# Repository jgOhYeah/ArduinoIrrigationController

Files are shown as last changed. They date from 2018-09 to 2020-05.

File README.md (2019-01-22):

# Arduino Irrigation Controller
An irrigation controller for a small farm that remotely controls a set of linear actuators that raise and lower flaps over pipes.
## This is still a WORK IN PROGRESS!
I am mainly using this repository to transfer files! If you are interested in using this, have a look at `SlaveUnit/SlaveUnit3.6` and `Controller/3.4`. **There will be bugs!**
## Links
Most of these notes are very out of date and based off old versions - I have not properly updated the documentation for quite a while!
- [User Guide](Documentation/UserGuide.md)
- [Technical Notes and rambling](Documentation/TechnicalNotes)
# Parts
## Master
- Arduino Mega
- 3 buttons (left, right and select)
- Character lcd (currently using a 40 by 2 lcd, also works on a 16 by 2 lcd by selecting macros and `#defines`, could be modified for a 20 by 4).
## Slaves
- Arduino Uno / Nano / Atmega328p driving a H bridge motor driver to power a linear actuator opening and shutting the bay outlets

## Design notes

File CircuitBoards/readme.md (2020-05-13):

Please note that these are a work in progress.

The slave circuit and layout is about done, I am waiting to finish the slave design and build several of them to test lots of devices on the bus before I do the master board layout.

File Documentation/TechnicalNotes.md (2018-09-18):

# Arduino Irrigation Controller Technical Notes
## Links
- [Home Page](../README.md)
- [User Guide](Documentation/UserGuide.md)
## Error Codes
Here is a list of possible error codes that will be displayed on the main controller's lcd display. All error messages start with the up time at which they were encountered followed by the details.

### `hh:mm Bays x,y,z Disconnected`
This is the most common error and is displayed when the controller does not recieve an acknowledgement from the bay outlet. If all bay outlets are effected, `All` will be displayed instead of outlet numbers. Check that everything is connected properly and turned on.

### `hh:mm `
Blah blah blah
## LCD Layout
The main controller currently uses a 16 by 2 alphanumeric lcd display. This works fairly well for displaying the seven bays that this system was designed for, however you might want to get a bigger 20 by 4 lcd and adapt the code if you plan on having more bays.

The `*` (Astrixes) are used as buttons and can be clicked on by using the left and right buttons to navigate the cursor (black line under a character) and the select button to click it.
#### Main Screen
```
                     \/ A is an option to control all bays at once.
Bay Number -> 1234567A   hh:mm
Bay Status -> ???????*   *More
```
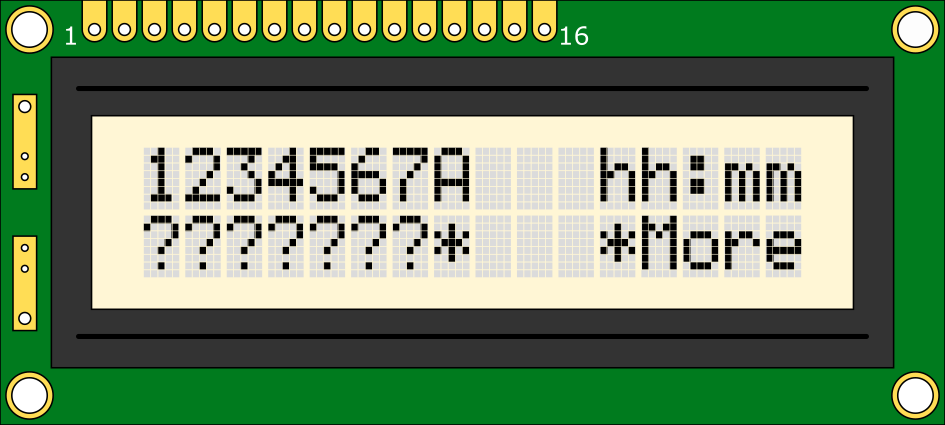
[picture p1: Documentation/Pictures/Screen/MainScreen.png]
Main Screen

#### More Options Screen
```
*Home *Reset All
*Last Error Msg
```
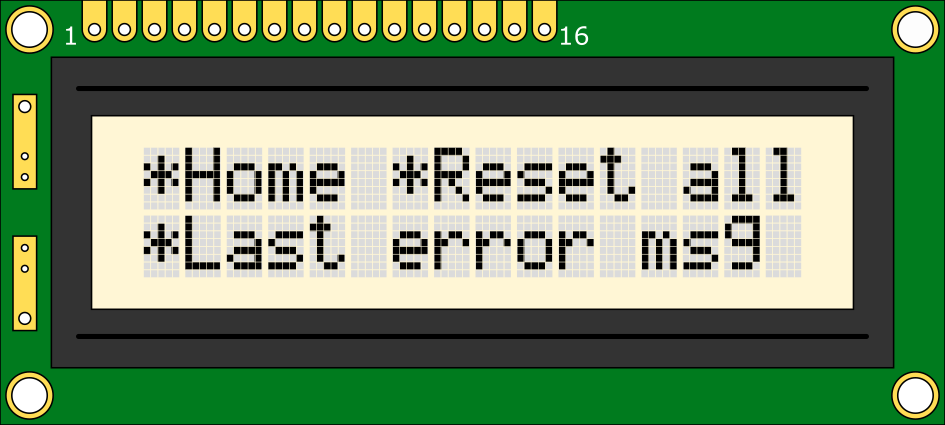
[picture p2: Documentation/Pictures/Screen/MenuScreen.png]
More Options Screen

#### Error Message Screen
```
*Home ERRORhh:mm
<Error message here. It can be scrolled as well!>
```
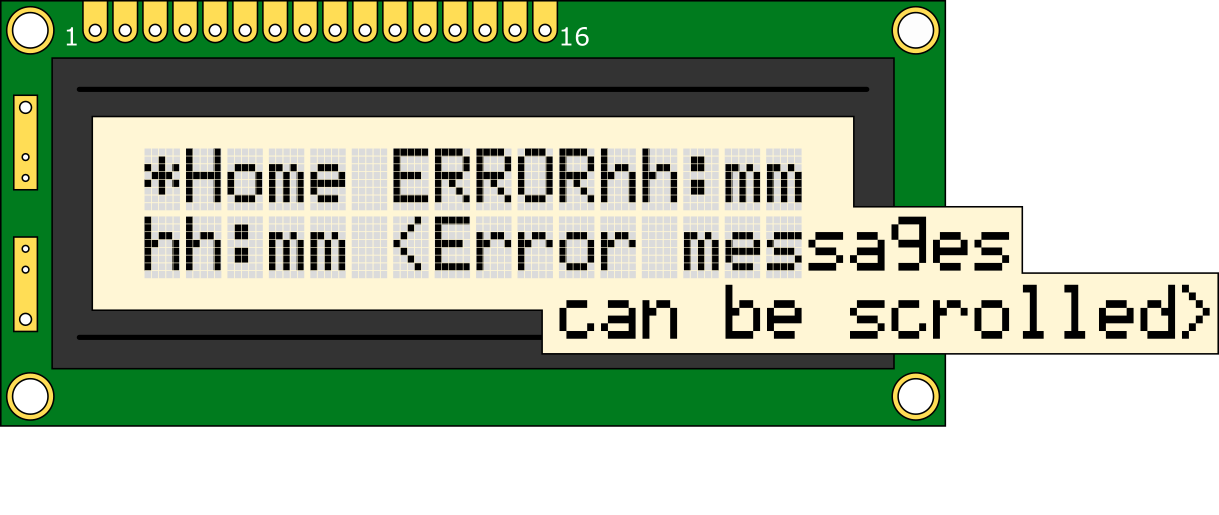
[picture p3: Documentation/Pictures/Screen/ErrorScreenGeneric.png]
Error Screen

## Communication
This system uses the PJON protocol using ThroughSerial over rs485. This protocol automatically handles error checking and making sure that packets go to where they need to go and are recieved. [Click Here](https://www.pjon.org/) to go to the PJON website.

The baud rate is set to 9600 by default. If there is large amount of data being lost, try slowing this down. The baud rate **must** be the same on all devices.

### Addresses
The bus id is set to 0.0.0.1 by default. It does not really matter as long as separate PJON networks are kept separate, but this can be changed as long as it is the same for all devices on this network.

The main controller's address is 255.

Slave addresses start at 40 for bay 1.
### Commands
The first byte of the payload in a packet contains the command. Subsequent bytes have the details.
#### `reportStatus` or `s`

The main controller sends this command when it first starts up to check which dbays are connected and see if they know their position (The main controller might be reset while everything else still has power...).
#### `overwriteStatus` or `w`
This is sent from a slave to the main controller to change what state it thinks it is in. this is used if a user presses the button on a bay outlet to change its position or after the slave has recieved a `reportStatus` command.

1 byte after the command contains the status.

#### `reset` or `x`
This is a broadcast command that should in theory reset the whole system.

#define setStatus "r"

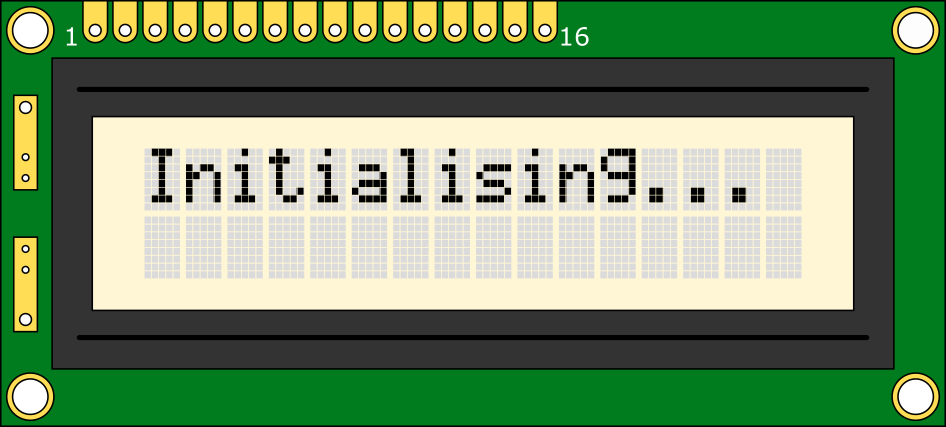
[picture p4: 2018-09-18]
Documentation/Pictures/Screen/InitScreen.png

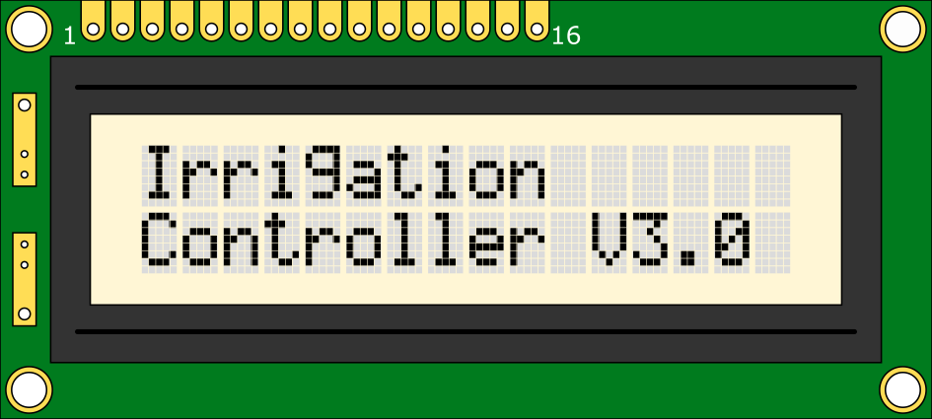
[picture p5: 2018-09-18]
Documentation/Pictures/Screen/StartupScreen.png

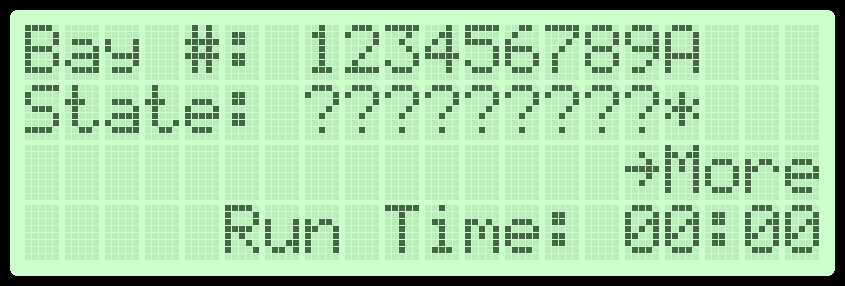
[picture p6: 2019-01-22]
OtherStuff/LCD_Plans/screenshot (2).png

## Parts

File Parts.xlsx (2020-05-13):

Item | Number On Master | Number on Slave | Total Number | Cost at number | Total Part Cost | Possible source | Total Cost | Number of slaves | Number of masters
Buttons | 3 | 1 | 10 | 4.45 | 44.5 | https://www.jaycar.com.au/ip67-rated-dome-pushbutton-switch-red/p/SP0657 | 884.5 | 7 | 1
Slave Box | 0 | 1 | 7 | 10 | 70
Master Box | 1 | 0 | 1 | 15 | 15
Linear Actuators | 0 | 1 | 7 | 100 | 700
Motor Driver | 0 | 1 | 7 | 3 | 21
Slave Circuit boards | 0 | 1.43 | 10 | 1 | 10
Master Circuit boards | 1 | 0 | 1 |  | 0
Slave Box | 0 | 1 | 7 |  | 0
Master Box | 1 | 0 | 1 |  | 0
Plugs | 1 | 1 | 8 |  | 0
Sockets | 2 | 2 | 16 |  | 0
Cable Glands | 1 | 1 | 8 | 3 | 24
 |  |  | 0 |  | 0
 |  |  | 0 |  | 0
 |  |  | 0 |  | 0
 |  |  | 0 |  | 0

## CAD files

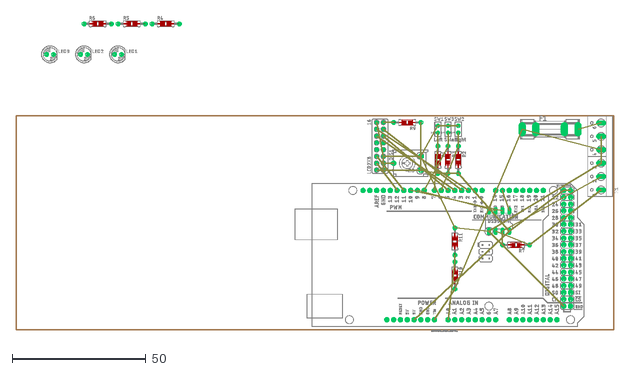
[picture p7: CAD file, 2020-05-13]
CircuitBoards/IrrigationControllerMaster/IrrigationControllerMaster.dxf
224.7 x 117.8

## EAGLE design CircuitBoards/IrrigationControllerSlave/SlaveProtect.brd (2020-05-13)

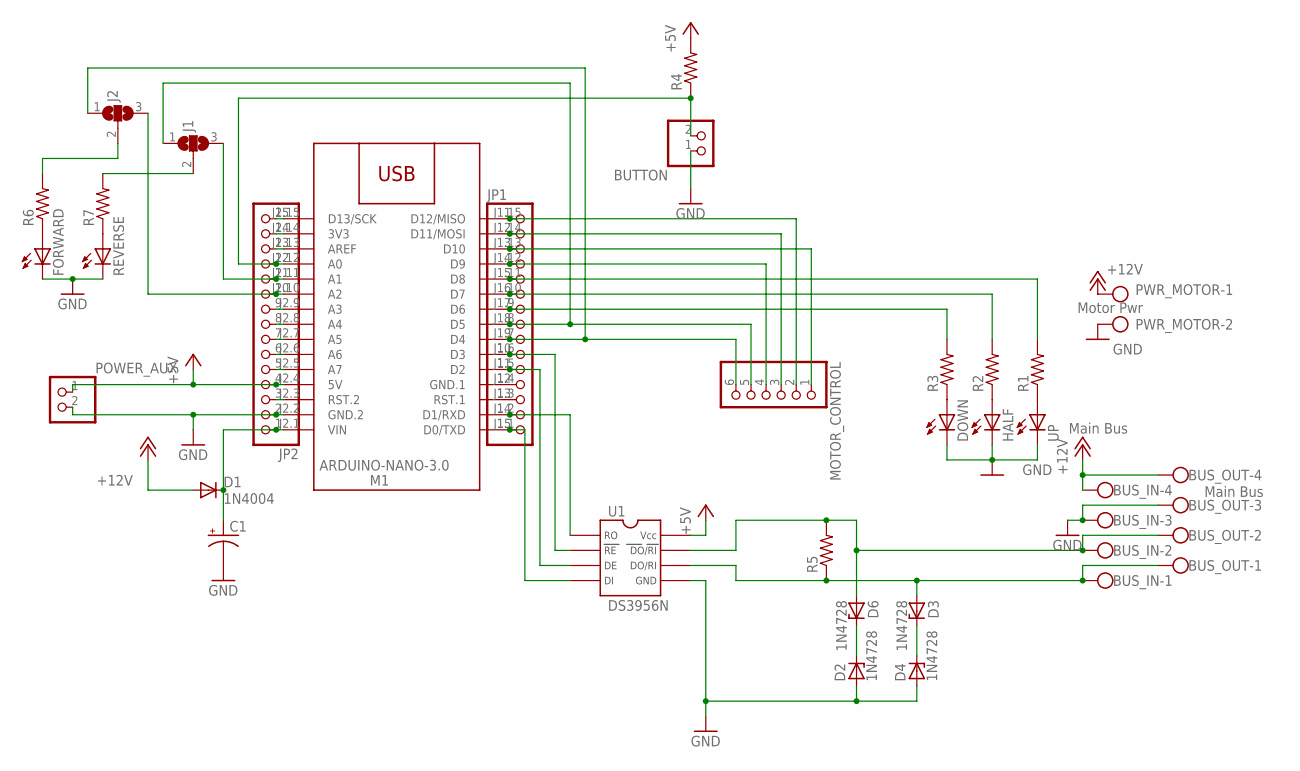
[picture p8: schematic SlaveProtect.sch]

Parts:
BUS_IN: Main Bus; W237-4
BUS_OUT: Main Bus; W237-4
BUTTON: PINHD-1X2; 1X02
C1: CPOL-USE3.5-10; E3,5-10
D1: 1N4004; DO41-10
D2, D3, D4, D6: 1N4728; DO41Z10
DOWN: LED5MM
FORWARD: LED5MM
HALF: LED5MM
J1, J2: SJ2W; SJ_2
JP1, JP2: PINHD-1X15-CB; 1X15-CB
M1: ARDUINO-NANO-3.0
MOTOR_CONTROL: PINHD-1X6; 1X06
POWER_AUX: PINHD-1X2; 1X02
PWR_MOTOR: Motor Pwr; W237-102
R1, R2, R3, R4, R5, R6, R7: FLIPFLOP-RES; 0805-THM
REVERSE: LED5MM
U1: DS3956N; DIL08
UP: LED5MM

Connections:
+5V: JP2.4, M1.J2.4 (5V), POWER_AUX.1, R4.2, U1.8 (VCC)
+12V: BUS_IN.4, BUS_OUT.4, D1.A, PWR_MOTOR.1
GND: BUS_IN.3, BUS_OUT.3, BUTTON.1, C1.-, D2.A, D4.A, DOWN.K (C), FORWARD.K (C), HALF.K (C), JP2.2, M1.J2.2 (GND.2), POWER_AUX.2, PWR_MOTOR.2, REVERSE.K (C), U1.5 (GND), UP.K (C)
unnamed: R1.1, UP.A
unnamed: HALF.A, R2.1
unnamed: DOWN.A, R3.1
unnamed: BUTTON.2, JP2.12, M1.J2.12 (A0), R4.1
unnamed: BUS_IN.1, BUS_OUT.1, D3.A, R5.1, U1.6 (DO/RI)
unnamed: BUS_IN.2, BUS_OUT.2, D6.A, R5.2, U1.7 (_DO/RI_)
unnamed: JP1.10, M1.J1.6 (D3), U1.2 (_RE_)
unnamed: JP1.11, M1.J1.5 (D2), U1.3 (DE)
unnamed: JP1.14, M1.J1.2 (D1/RXD), U1.1 (RO)
unnamed: JP1.15, M1.J1.1 (D0/TXD), U1.4 (DI)
unnamed: JP1.7, M1.J1.9 (D6), R3.2
unnamed: JP1.6, M1.J1.10 (D7), R2.2
unnamed: JP1.5, M1.J1.11 (D8), R1.2
unnamed: J1.1, JP1.8, M1.J1.8 (D5), MOTOR_CONTROL.5
unnamed: J1.2, R7.2
unnamed: C1.+, D1.C, JP2.1, M1.J2.1 (VIN)
unnamed: FORWARD.A, R6.1
unnamed: R7.1, REVERSE.A
unnamed: D2.C, D6.C
unnamed: D3.C, D4.C
unnamed: JP2.3, M1.J2.3 (RST.2)
unnamed: JP2.5, M1.J2.5 (A7)
unnamed: JP2.6, M1.J2.6 (A6)
unnamed: JP2.7, M1.J2.7 (A5)
unnamed: JP2.8, M1.J2.8 (A4)
unnamed: JP2.9, M1.J2.9 (A3)
unnamed: J2.3, JP2.10, M1.J2.10 (A2)
unnamed: J1.3, JP2.11, M1.J2.11 (A1)
unnamed: J2.1, JP1.9, M1.J1.7 (D4), MOTOR_CONTROL.6
unnamed: JP2.13, M1.J2.13 (AREF)
unnamed: JP2.14, M1.J2.14 (3V3)
unnamed: JP2.15, M1.J2.15 (D13/SCK)
unnamed: JP1.1, M1.J1.15 (D12/MISO), MOTOR_CONTROL.2
unnamed: JP1.2, M1.J1.14 (D11/MOSI), MOTOR_CONTROL.3
unnamed: JP1.3, M1.J1.13 (D10), MOTOR_CONTROL.1
unnamed: JP1.12, M1.J1.4 (GND.1)
unnamed: JP1.13, M1.J1.3 (RST.1)
unnamed: JP1.4, M1.J1.12 (D9), MOTOR_CONTROL.4
unnamed: J2.2, R6.2

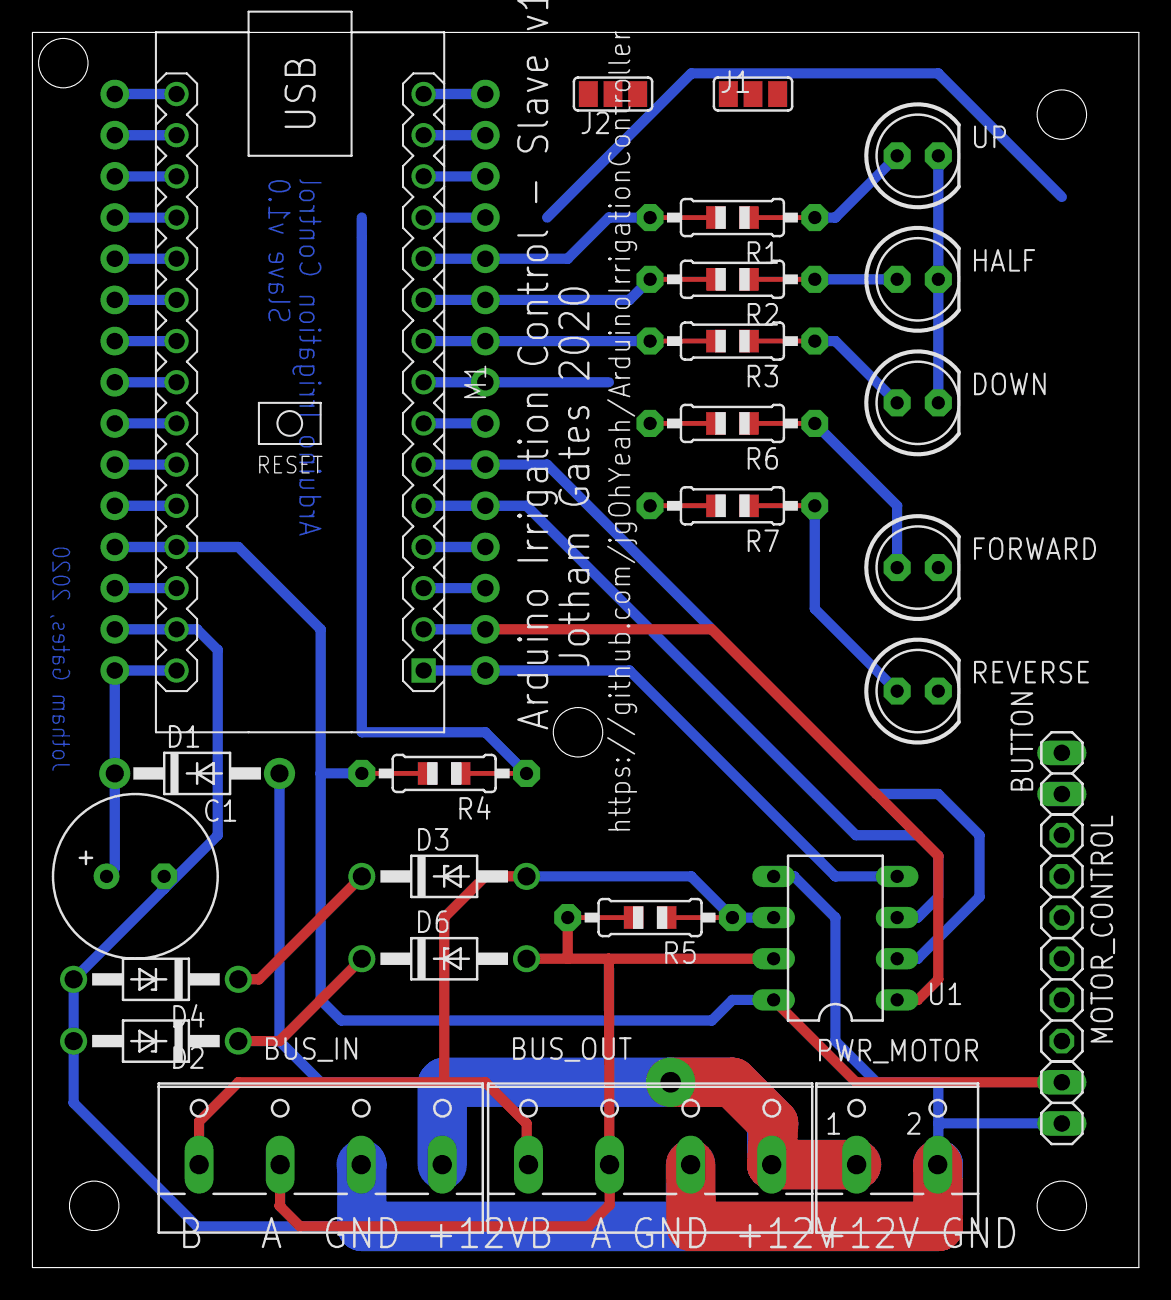
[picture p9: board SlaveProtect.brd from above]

Board: 2 copper layers, 68.2 x 76.2 mm, 30 parts (0 on the bottom side), 42 nets.

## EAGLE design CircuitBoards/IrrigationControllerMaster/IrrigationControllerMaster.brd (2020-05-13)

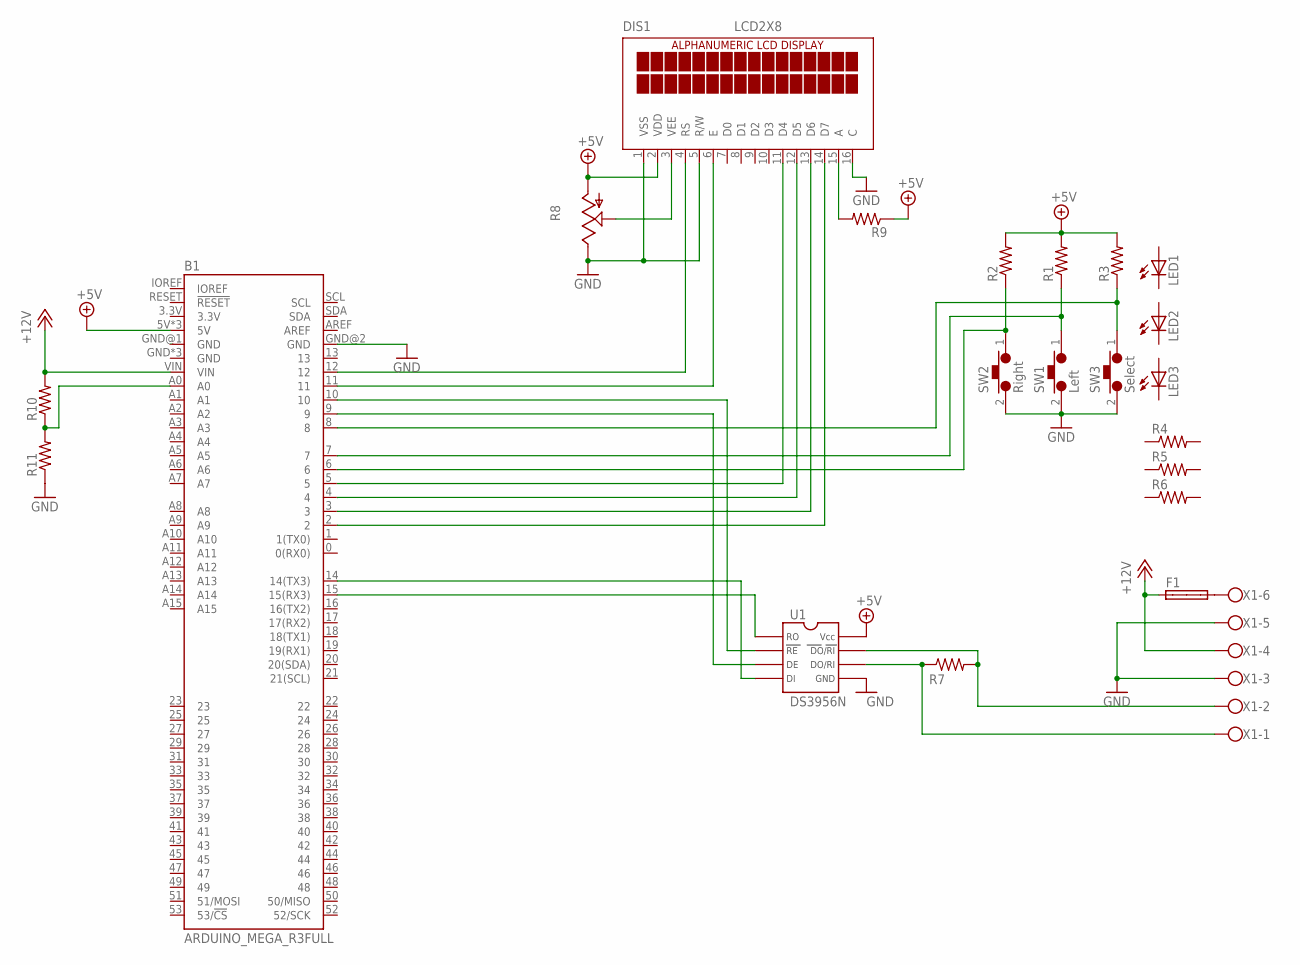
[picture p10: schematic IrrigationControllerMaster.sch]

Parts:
B1: ARDUINO_MEGA_R3FULL; ARDUINO_MEGA_NO_SILK
DIS1: LCD2X8; 2X08_JAYCAR
F1: SHK20L
LED1, LED2, LED3: LED5MM
R1, R2, R3, R4, R5, R6, R7, R9, R10, R11: FLIPFLOP-RES; 0805-THM
R8: TRIM_US-ECP10S; ECP10S
SW1: Left; 2PIN
SW2: Right; 2PIN
SW3: Select; 2PIN
U1: DS3956N; DIL08
X1: W237-6

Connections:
+5V: B1.5V, B1.5V@1 (5V), B1.5V@2 (5V), DIS1.2 (VDD), R1.2, R2.2, R3.2, R8.A, R9.1, U1.8 (VCC)
+12V: B1.VIN, F1.1A, R10.2, X1.4
GND: B1.GND@2 (GND), DIS1.1 (VSS), DIS1.5 (R/W), DIS1.16 (C), R8.E, R11.1, SW1.2, SW2.2, SW3.2, U1.5 (GND), X1.3, X1.5
unnamed: R7.2, U1.7 (_DO/RI_), X1.2
unnamed: R7.1, U1.6 (DO/RI), X1.1
unnamed: B1.7, R1.1, SW1.1
unnamed: B1.6, R2.1, SW2.1
unnamed: B1.8, R3.1, SW3.1
unnamed: DIS1.3 (VEE), R8.S
unnamed: B1.12, DIS1.4 (RS)
unnamed: B1.11, DIS1.6 (E)
unnamed: B1.5, DIS1.11 (D4)
unnamed: B1.4, DIS1.12 (D5)
unnamed: B1.3, DIS1.13 (D6)
unnamed: B1.2, DIS1.14 (D7)
unnamed: B1.15 (15(RX3)), U1.1 (RO)
unnamed: B1.14 (14(TX3)), U1.4 (DI)
unnamed: B1.10, U1.2 (_RE_)
unnamed: B1.9, U1.3 (DE)
unnamed: DIS1.15 (A), R9.2
unnamed: B1.A0, R10.1, R11.2
unnamed: F1.2A, X1.6

Board: 2 copper layers, 22 parts (0 on the bottom side), 22 nets, no tracks yet.

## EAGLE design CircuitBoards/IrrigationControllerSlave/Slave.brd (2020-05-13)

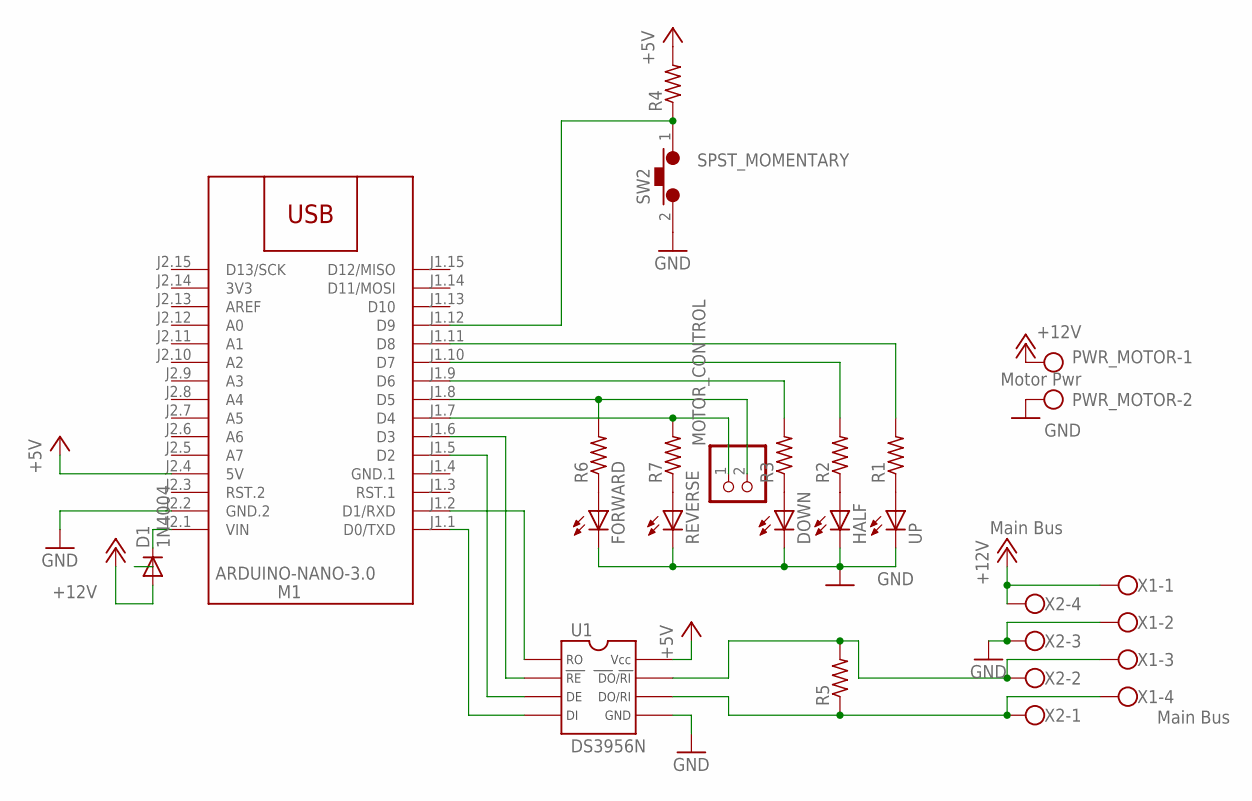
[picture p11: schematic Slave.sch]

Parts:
D1: 1N4004; DO41-10
DOWN: LED5MM
FORWARD: LED5MM
HALF: LED5MM
M1: ARDUINO-NANO-3.0
MOTOR_CONTROL: PINHD-1X2; 1X02
PWR_MOTOR: Motor Pwr; W237-102
R1, R2, R3, R4, R5, R6, R7: FLIPFLOP-RES; 0805-THM
REVERSE: LED5MM
SW2: SPST_MOMENTARY; 2PIN
U1: DS3956N; DIL08
UP: LED5MM
X1, X2: Main Bus; W237-4

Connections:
3V3: M1.J2.14 (3V3)
+5V: M1.J2.4 (5V), R4.2, U1.8 (VCC)
+12V: D1.A, PWR_MOTOR.1, X1.1, X2.4
GND: DOWN.K (C), FORWARD.K (C), HALF.K (C), M1.J2.2 (GND.2), PWR_MOTOR.2, REVERSE.K (C), SW2.2, U1.5 (GND), UP.K (C), X1.2, X2.3
GND.1: M1.J1.4 (GND.1)
unnamed: R1.1, UP.A
unnamed: HALF.A, R2.1
unnamed: DOWN.A, R3.1
unnamed: M1.J1.12 (D9), R4.1, SW2.1
unnamed: R5.1, U1.6 (DO/RI), X1.4, X2.1
unnamed: R5.2, U1.7 (_DO/RI_), X1.3, X2.2
unnamed: M1.J1.6 (D3), U1.2 (_RE_)
unnamed: M1.J1.5 (D2), U1.3 (DE)
unnamed: M1.J1.2 (D1/RXD), U1.1 (RO)
unnamed: M1.J1.1 (D0/TXD), U1.4 (DI)
unnamed: M1.J1.9 (D6), R3.2
unnamed: M1.J1.10 (D7), R2.2
unnamed: M1.J1.11 (D8), R1.2
unnamed: M1.J1.8 (D5), MOTOR_CONTROL.2, R6.2
unnamed: M1.J1.7 (D4), MOTOR_CONTROL.1, R7.2
unnamed: D1.C, M1.J2.1 (VIN)
unnamed: FORWARD.A, R6.1
unnamed: R7.1, REVERSE.A

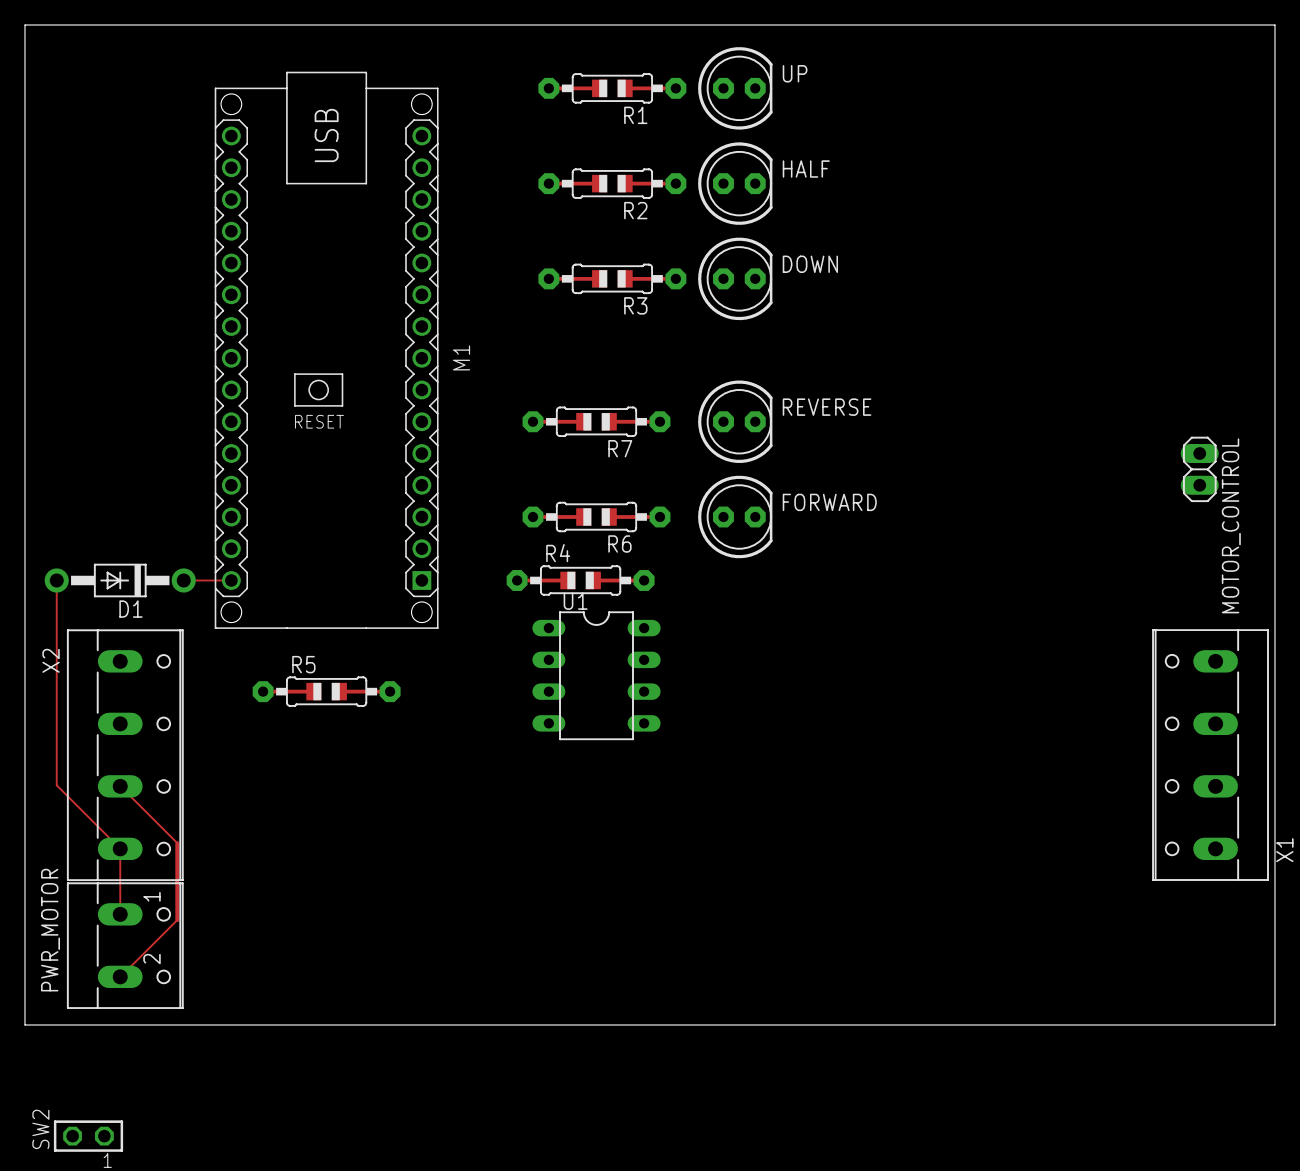
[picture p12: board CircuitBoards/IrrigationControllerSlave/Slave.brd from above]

Board: 2 copper layers, 100.0 x 80.0 mm, 20 parts (0 on the bottom side), 21 nets.

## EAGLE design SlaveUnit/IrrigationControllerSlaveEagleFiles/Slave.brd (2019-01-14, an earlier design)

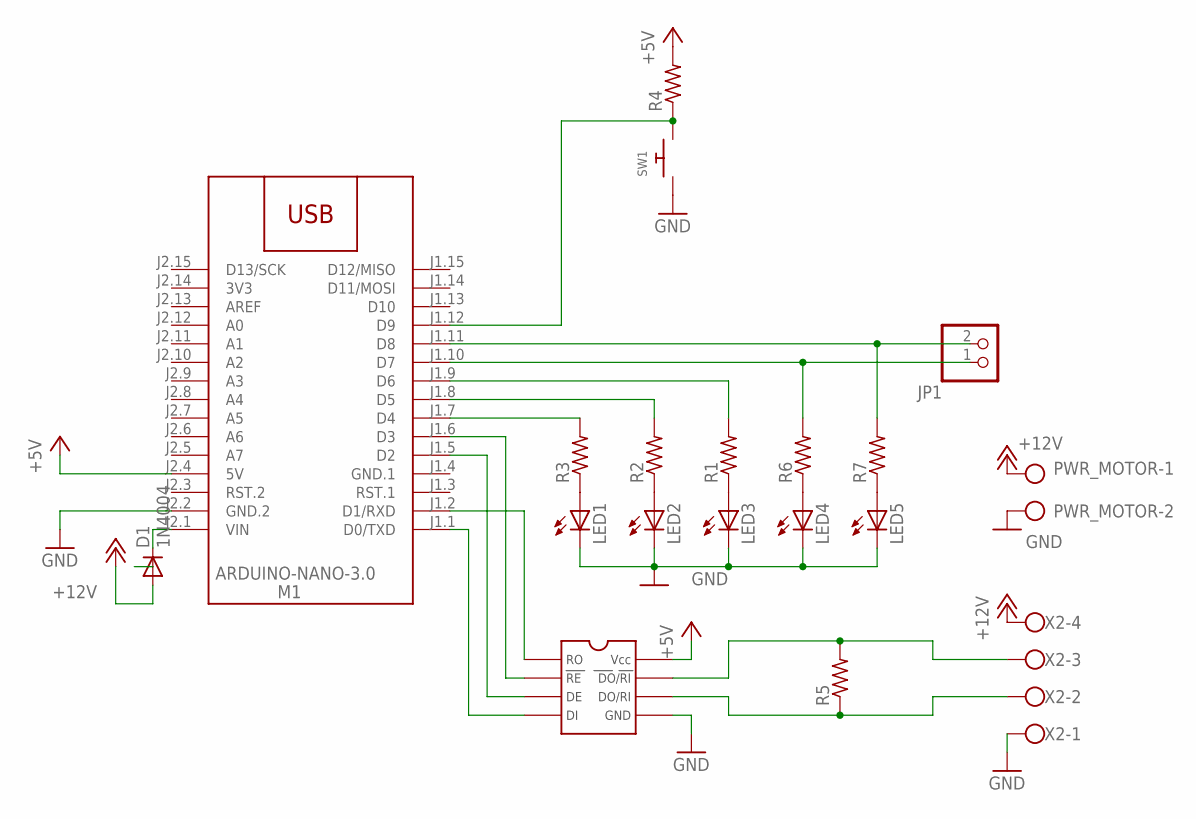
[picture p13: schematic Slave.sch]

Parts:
D1: 1N4004; DO41-10
JP1: PINHD-1X2; 1X02
LED1, LED2, LED3, LED4, LED5: LED5MM
M1: ARDUINO-NANO-3.0
PWR_MOTOR: W237-102
R1, R2, R3, R4, R5, R6, R7: FLIPFLOP-RES; 0805-THM
SW1: SWITCH_PUSHBUTTONEVQ-PE; TACT_PANA-EVQ
U1: DS3956N; DIL08
X2: W237-4

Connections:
3V3: M1.J2.14 (3V3)
+5V: M1.J2.4 (5V), R4.2, U1.8 (VCC)
+12V: D1.A, PWR_MOTOR.1, X2.4
GND: LED1.K (C), LED2.K (C), LED3.K (C), LED4.K (C), LED5.K (C), M1.J2.2 (GND.2), PWR_MOTOR.2, SW1.P$1, U1.5 (GND), X2.1
GND.1: M1.J1.4 (GND.1)
unnamed: LED3.A, R1.1
unnamed: LED2.A, R2.1
unnamed: LED1.A, R3.1
unnamed: M1.J1.12 (D9), R4.1, SW1.P$2
unnamed: R5.1, U1.6 (DO/RI), X2.2
unnamed: R5.2, U1.7 (_DO/RI_), X2.3
unnamed: M1.J1.6 (D3), U1.2 (_RE_)
unnamed: M1.J1.5 (D2), U1.3 (DE)
unnamed: M1.J1.2 (D1/RXD), U1.1 (RO)
unnamed: M1.J1.1 (D0/TXD), U1.4 (DI)
unnamed: M1.J1.7 (D4), R3.2
unnamed: M1.J1.8 (D5), R2.2
unnamed: M1.J1.9 (D6), R1.2
unnamed: JP1.2, M1.J1.11 (D8), R7.2
unnamed: JP1.1, M1.J1.10 (D7), R6.2
unnamed: D1.C, M1.J2.1 (VIN)
unnamed: LED4.A, R6.1
unnamed: LED5.A, R7.1

Board: 2 copper layers, 19 parts (0 on the bottom side), 21 nets, no tracks yet.

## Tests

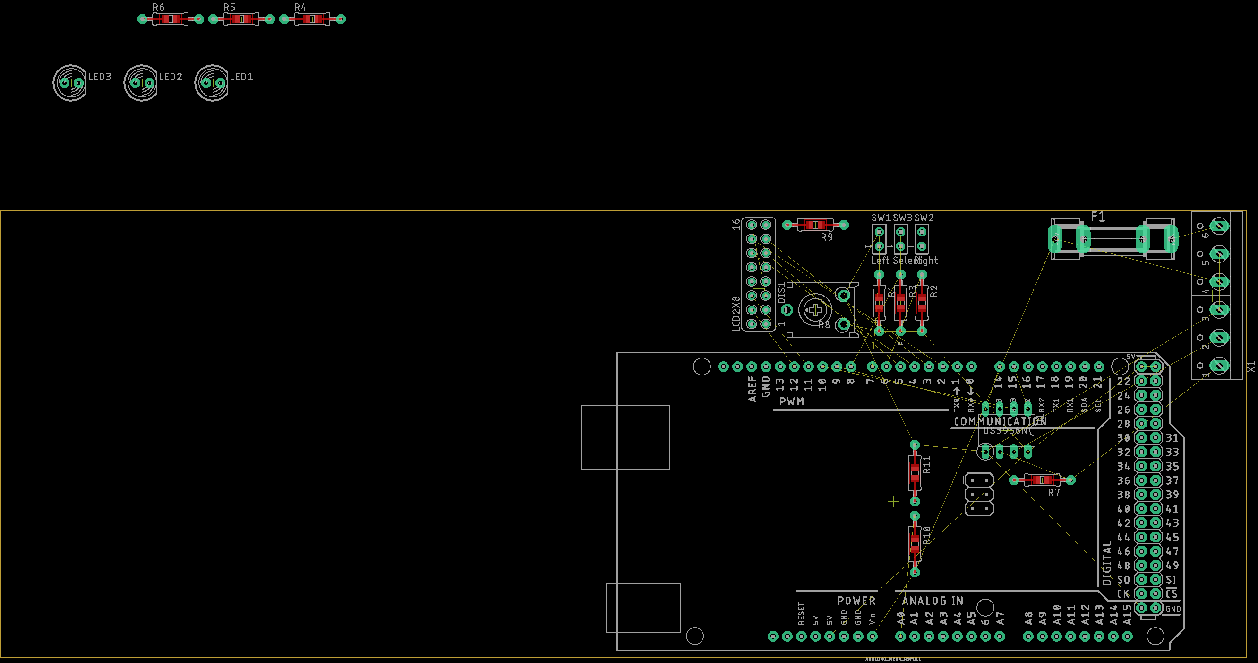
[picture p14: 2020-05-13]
CircuitBoards/IrrigationControllerMaster/20190415_test.png

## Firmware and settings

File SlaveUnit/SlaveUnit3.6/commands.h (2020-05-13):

/*A set of commands and constants that are the same on the master*/
//Commands
#define CMD_REPORT_STATUS 's'
#define CMD_OVERWRITE_STATUS 'w'
#define CMD_RESET 'x'
#define CMD_SET_STATUS 'r'
#define CMD_SET_EEPROM 'm'
#define CMD_READ_EEPROM 'n'
#define CMD_REPORT_EEPROM 'o' //The reply message sent to CMD_READ_EEPROM
#define CMD_ERROR 'E' //E followed by the error code (byte) and data

//EEPROM value codes
#define SETTING_ADDRESS 'a'
#define SETTING_HALF_POS 'b'
#define SETTING_UP_SPEED 'c'
#define SETTING_DOWN_SPEED 'd'
#define SETTING_BAUD_RATE 'e'

//Bay states
#define STATE_UNKOWN 0
#define STATE_SHUT 1
#define STATE_HALF 2
#define STATE_OPEN 3
#define STATE_NOT_PRESENT 4

//Error codes
#define ERR_INVALID_ADDRESS 50
#define ERR_PACKET_LENGTH 51
#define ERR_UNKOWN_COMMAND 52
#define ERR_UNKOWN_PARAMETERS 53
#define ERR_OUTSIDE_RANGE 54
#define ERR_UNEXPECTED_PACKET 55
#define ERR_UNDERVOLTAGE 56

//Other common values
#define NONEXISTANT_CALLBACK 254

//Shared PJON settings/ default values
#define PJON_BUS_ID {0,0,1,73} //An official bus id for rs485 in Northern Victoria, registered 15/01/2018
#define DEFAULT_ADDRESS 40 //The default address of the slave
#define DEFAULT_UP_TIME 24000 //These defaults are offone of the inital batch of linear actuators running off a 12v switchmode power supply - will not be right for other ones
#define DEFAULT_DOWN_TIME 23700
#define DEFAULT_HALF_POS 50
#define DEFAULT_BAUD_RATE 38400 //Default baud rate to reset the value stored in eeprom to.
#define RESET_SETTINGS_EEPROM B10011001 //Random number Change this to force the slave to reset all eeprom to the default when it starts up for the first time after programming. - If the arduino is new, the value will probably be 255

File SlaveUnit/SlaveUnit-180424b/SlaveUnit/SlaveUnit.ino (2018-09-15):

#include <EEPROM.h>
#include <LongDistanceSerial.h>
#include <buttons.h>
#include "defines.h"

LongDistanceSerial serialCom(&Serial,1200,serialEnablePin,startChar,endChar,0);
Button builtinButton;

void setup() {
  serialCom.begin();
  pinMode(LED_BUILTIN,OUTPUT);
  for(byte i = shutLed; i <= openLed; i ++) {
    pinMode(i,OUTPUT);
  }
  pinMode(motorA,OUTPUT);
  pinMode(motorB,OUTPUT);
  digitalWrite(LED_BUILTIN,LOW);

  builtinButton.assign(buttonPin);
  builtinButton.setMode(buttonMode);
  builtinButton.setTimer(buttonTimer);
  builtinButton.setRefresh(buttonRefresh);
  //If button was pressed while starting up, enter programming mode
  if(builtinButton.check() == ON) {
    setEepromSettings();
  }
  bayOpenTime = EEPROM.read(bayOpenTimeAddress);
  bayCloseTime = EEPROM.read(bayCloseTimeAddress);
  bayHalfTimeFraction = EEPROM.read(bayHalfTimeFractionAddress);
  deviceAddress = EEPROM.read(deviceIdAddress);
  //Make a random seed based on the device address so differs from others hopefully
  randomSeed(deviceAddress);
}
void loop() {
  byte address, commandOne, commandTwo; 
  byte recieveStatus = serialCom.recieveCommand(address, commandOne, commandTwo,serialRecieveTimeout);
  //Recieve any commands with either the individual device address or all of them. Just ignore errors for now
  if(recieveStatus == serialSuccess && (address == deviceAddress || address == allDevices)) {
    Serial.println(bayStatus);
    //motorControl(commandOne);
  }
  if(bayStatus == bayUnknown) {
    scrollLeds();
  }
  if(builtinButton.check() == ON) {
    bayStatus++;
    if(bayStatus > bayOpen) {
      bayStatus = bayShut;
    }
    Serial.println(bayStatus);
  }
  //Stop the motor if a time was set to turn off
  /*if(millis() >= shutoffTime && shutoffTime != 0) {
    haltMotor();
    shutoffTime = 0;
  }*/
}
void sendReply(byte commandOne, byte commandTwo) {
  delay(random(maxDelayTime));
  serialCom.sendCommand(deviceAddress,commandOne,commandTwo,enableLineWait);
}
void scrollLeds() {
  //Every few seconds
  static unsigned long nextTime = 0;
  static byte currentLedOn = 0;
  unsigned long milliSeconds = millis();
  if(milliSeconds >= nextTime) {
    nextTime = milliSeconds + unknownFlashSpeed;
    currentLedOn++;
    if(currentLedOn > 2) {
      currentLedOn = 0;
    }
    //Crude scanning - nightrider with limited leds
    switch(currentLedOn) {
      case 0:
        digitalWrite(shutLed,LOW);
        digitalWrite(halfLed,HIGH);
        digitalWrite(openLed,LOW);
        break;
      case 1:
        digitalWrite(shutLed,LOW);
        digitalWrite(halfLed,LOW);
        digitalWrite(openLed,HIGH);
        break;
      case 2:
        digitalWrite(shutLed,HIGH);
        digitalWrite(halfLed,LOW);
        digitalWrite(openLed,LOW);
        break;
    }
  }
}
void flashLeds() {
  static bool ledsOn = false;
  static unsigned long nextTime = 0;
  unsigned long milliSeconds = millis();
  if(milliSeconds >= nextTime) {
    nextTime = milliSeconds + settingsFlashSpeed;
    ledsOn = !ledsOn;
    for(byte i = shutLed; i <= openLed; i ++) {
      digitalWrite(i,ledsOn);
    }
  }
}
void openMotorDir() {
  digitalWrite(motorA,HIGH);
  digitalWrite(motorB,LOW);
}
void closeMotorDir() {
  digitalWrite(motorA,LOW);
  digitalWrite(motorB,HIGH);
}
void haltMotor() {
  digitalWrite(motorA,LOW);
  digitalWrite(motorB,LOW);
}
/*void motorControl(byte state){
  switch(state) {
    case reportStatus:
      sendReply(bayStatus,serialWrite);
      break;
    case reset:
      //Reset when find the code
      while(true);
      break;
    case bayShut:
      bayStatus = bayShut;
      sendReply(bayStatus,serialRead);
      closeMotorDir();
      digitalWrite(shutLed,HIGH);
      digitalWrite(halfLed,LOW);
      digitalWrite(openLed,LOW);
      break;
    case bayHalf:
      bayStatus = bayHalf;
      sendReply(bayStatus,serialRead);
      digitalWrite(shutLed,LOW);
      digitalWrite(halfLed,HIGH);
      digitalWrite(openLed,LOW);
      break;
    case bayOpen:
      bayStatus = bayOpen;
      sendReply(bayStatus,serialRead);
      digitalWrite(shutLed,LOW);
      digitalWrite(halfLed,LOW);
      digitalWrite(openLed,HIGH);
      break;
  }
}
*/

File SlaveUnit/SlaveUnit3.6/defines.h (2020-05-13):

//Software Version of the slave
#define SOFTWARE_VERSION " V3.6.1"
#define MASTER_ID 255
byte myId; //44 is bay 5, 45 is bay 6... 40 is bay 1
uint8_t busId[4] = PJON_BUS_ID;
//#define DEFAULT_BAUD_RATE 9600 //Default baud rate to reset the value stored in eeprom to.
//Stuff to generate strings from #define values
#define XSTR(a) STR(a)
#define STR(a) #a
#define BAUD_RATE_STRING STR(DEFAULT_BAUD_RATE)
//#define ledFlashSpeed 500
#define LONG_PRESS_TIME 5000
#define SERIAL_TIMEOUT 600000 //11 minutes
#define SERIAL_INPUT_MAX_DIGITS 10 //Maximum number of digits that can be entered when typing something. - 10 digits is the maximum a long and unsigned long can hold
#define SERIAL_INPUT_TIMEOUT_VALUE -2
//#define ENABLE_RESET //Do not define this if this code is running on an atmega 328p running the arduino nano bootloader! (arduino uno bootloader is fine)
char bayStatus = STATE_UNKOWN;
#define STRINGIFY(x) #x
#define TOSTRING(x) STRINGIFY(x)

#define MAX_BAY_TIME 43383508 //(2^32-1)/99 is the largest number you can have before it possibly overflows
#define MIN_SERIAL_BAUD 50
#define MAX_SERIAL_BAUD 2000000

byte halfwayPos; //25 Percent from the bottom
unsigned long downTravelSpeed; //Default 26000
unsigned long upTravelSpeed; //Default 24000

unsigned long halfUpTime; //Will be worked out using values from EEPROM on start
unsigned long halfDownTime;

unsigned long startDelayTime = 0;
unsigned long timeAtDown = 0;
unsigned long timeAtOpen = 0;

//ADDRESSES OF VALUES STORED IN EEPROM
//Longs take 4 bytes, ints take 2 and bytes take 1
#define EEPROM_ADDRESS 0 //1 byte
#define EEPROM_HALFWAY_POS 1 //1 byte
#define EEPROM_DOWN_TRAVEL_SPEED 2 //4 bytes
#define EEPROM_UP_TRAVEL_SPEED 6 //4 bytes
#define EEPROM_SERIAL_BAUD 10 //4 bytes
//#define EEPROM_BUS_ID 14 //4 bytes (each is a separate number though)
#define EEPROM_FIRST_START_UP 14//1 byte - set to a random number (B10011001) if the slave has started up before, otherwise burn the default values into the other eeprom settings and set this to this number - factory reset


//Leds
#define MAX_CALLBACKS 5 //Increase it a bit to be safe
#define FAST_FLASH_RATE 100
#define SLOW_FLASH_RATE 1000

#define LEDS_STEADY 0
#define LEDS_FAST 1
#define LEDS_SLOW 2
#define LEDS_CHASE 3

byte ledStates = 0;
byte ledSavedStates = 0;
#define ERR_CALLBACK_BUFFER_FULL 255 //Because this bit of code is before the library is included
byte ledCallback = NONEXISTANT_CALLBACK; //Set the index to be inactive so it doesn;t cancel a callback as it starts.
byte ledSpecialCallback = NONEXISTANT_CALLBACK; //Only used for special occasions.
byte bayMovedCallback = NONEXISTANT_CALLBACK;
bool isUndervoltage = false;
/* ledStates structure in binary:
 * ZZYYYXXX
 * Where:
 *   ZZ is the mode the leds should be in.
 *   YYY is the current state of each led (up, half, down in that order - 0 = off, 1 = on) - also the initial state
 *   XXX is if the led state should be changed when updated. - In chasing mode this is also the stage that the sequence is up to.
 * Examples:
 *   ZZ YYY XXX
 *   00 100 000 = The LEDs on steady, Up led starting on, both others off, do not change the state at any time.
 *   01 010 110 = The LEDs flashing fast, Up and Down LEDs starting off while the Half LED starting on, Only update the Up and Half led when it is time to change their state (Down led stays off)
 *   10 111 111 = Slow flash, All LEDs starting on, all LEDs flashing.
 *   11 111 111 = Chasing - All LEDs involved.
*/

//Debugging macros to only enable debugging certain parts if debug is defined.
#if defined(DEBUG_CALLBACK_LIBRARY_ENABLE) && defined(DEBUG_ENABLE) //Used for the callbacks library to send serial data.
  #define DEBUG_CALLBACKS
#endif
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

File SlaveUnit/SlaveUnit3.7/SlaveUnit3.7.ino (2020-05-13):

#include "commands.h"
#include "settings.h"
#include "defines.h"
/* Include Async ACK code setting PJON_INCLUDE_ASYNC_ACK as true before including PJON.h */
#define PJON_INCLUDE_ASYNC_ACK true
#include <PJON.h>
#include <ButtonOnPress.h>
#include <PollingCallback.h>
#include <EEPROM.h>
// <Strategy name> bus(selected device id)
PJON<ThroughSerial> bus(busId, DEFAULT_ADDRESS); //44 is the default id and will be overwritten by the one from EEPROM
ButtonOnPress button(PIN_BUTTON,150,LOW,false);
PollingCallback callback; //Make a callback object to manage the callbacks.

void setup() {
  setBaudRate();
  setupSerial();
  loadSettings();
  button.begin();
  setupOutputs();
  checkFirstStart(); //Set the default eeprom settings if this is the first time the arduino has ever started up with this program
  checkForSettings();
  updateBay(bayStatus); //Set the leds up
  housekeeping();
  callback.add(5000,true,housekeeping); //Mostly debugging stuff that does not need to be done that often
}

void loop() {
  bus.update();
  bus.receive();
  checkButtons();
  callback.check();
}

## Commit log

2018-09-15 Originl Code
    [LCDPlan.xlsx]
2018-10-07 Still Working
    [LCDPlan.xlsx]
2018-11-06 MelbourneCupWeekend, Fixed Crashes on master and started to add featurs to the slave.
    Also started to break defines.h into smaller files.
    Still to do: read/set EEPROM over PJON
    Flashing leds on the slave.
    EEPROM read/set on the master
    lorawan transiever on master to allow remotes to communicate?
    [20180923_Controller3.0_PJON.ino, OtherFunctions.ino, SlaveUnit3.5.ino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]
2018-11-08 Started to add eeprom editor to controller.
    Use the second latest dated code for the controller for the most stable
    [LCDPlan.xlsx]
2018-11-11 UpdateVersion, start to add remote setting of eeprom values to the up time
    [LCDPlan.xlsx]
2018-11-16 Started to add more usable buttons to set slave's eeprom settings. - Look at _NOTES.ino in the controller files for more info
2018-11-18 Improved error codes, bug fixes
    [ErrorCodes.xlsx]
2018-12-03 swapping computers - flashing .eds
    [defines.h, other.ino]
2018-12-03 Still flashing LEDs - not much extra
2018-12-05 Still working on flashing leds and callback functions
2018-12-09 DONE_FIXING_NAMING_CONVENTIONS_IN_SLAVE_3.6, Adding in led and callback libraries - minor changes to wording in callback library
2018-12-10 Adding to flashing leds
2018-12-28 Added Debug to callback library and fixed passing defines to it.
    [SlaveUnit3.6.ino, UI.ino, defines.h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]
2018-12-29 Fixed callback overloads and issues, improved debugging for each part with macros
    [SlaveUnit3.6.ino, UI.ino, defines.h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]
2019-01-03 Fixing eeprom settings and naming conventions in controller
    [ErrorCodes.xlsx]
2019-01-04 Updates, Master now uses callback library, bug fixes
    [Controller3.4.ino, OtherFunctions.ino, _NOTES.ino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]
2019-01-14 Bug fixes, a bit of modifying for different displays
    [Slave.brd, Slave.sch]
2020-05-13 Added schematics and slave board layout
    [2020Slave.brd, 2020Slave.sch, IrrigationControllerMaster.brd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]

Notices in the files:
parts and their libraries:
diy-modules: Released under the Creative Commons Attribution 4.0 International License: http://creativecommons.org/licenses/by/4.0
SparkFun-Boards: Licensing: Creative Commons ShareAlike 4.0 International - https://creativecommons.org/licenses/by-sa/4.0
